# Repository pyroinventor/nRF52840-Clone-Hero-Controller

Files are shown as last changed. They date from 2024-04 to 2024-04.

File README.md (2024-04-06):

# nRF52840-Clone-Hero-Controller

This is a custom BLE enabled clone hero (or other rythm game) controller built around a xiao nRF52840 board.

## Why did I build this?

I played Lego Rock Band on the wii as a kid, and recently discovered clone hero as an alternative that allows you to play custom songs, make your own charts, and can run on a potato. However, the cheap wii controllers I had were annoying to use with their membrane switches, chunky usb reciever, and unweildy size. This motivated me to build a custom guitar controller with mechanical switches, BLE for battery life, and a body of my own design.

   
  
Nostalgic, but improvable :)

## What's Clone Hero?

Clone hero is a rythm game similar to guitar hero or rock band. It's open source and can run on pretty much any computer.

  
  

You can configure almost any device to be used as an input, such as MIDI drums and keyboards, gamepads, or in my case a custom controller. 

  
  
  
  

## Why nRF52840?

I initially used an ESP32 for development and testing, but it ended up being too bulky and power hungry to run on the tiny lipo battery I wanted to use. This led me to choose the nRF52840 from Nordic Semiconductors. The nordic controller supports bluetooth low energy, it takes up about a quarter of the size, and sips power compared to an ESP32 even while transmitting (30mA vs 200+mA). It is a little more expensive, costing around $10 to the ESP32's $3, but the previously mentioned advantages make it worth the premium for me. 

  \
<a href="https://www.seeedstudio.com/Seeed-XIAO-BLE-nRF52840-p-5201.html">nRF52840 I used</a>                         
<a href="https://www.aliexpress.us/item/2251832863673404.html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">ESP32 I used</a>

## Body Design

To design the body, I traced an image of a stratocaster in Onshape, then after fixing some weird unruly spline points I was able to extrude it and add some triangular cutouts. It wasn't too difficult but it took a while to do by hand. The fretboard and headstock were designed the same way. 

  
   

 Here's the tele I designed. 
 
   

The strum bar was a little tricky to dial in and it took a few revisions, but this is what I landed on. 

   

## Parts

* 1 x Xiao nRF52840
* 8 x Low Profile Mechanical Switches (I used Gateron LP Reds)
  * 5 for frets, 2 for strum bar, and 1 for start
* Few feet of cat5 cable or several lengths of wire (9 conductors total)
* 14AWG Steel Wire or similar for strum bar axle
* 2 x small washers to fit wire 
* 3D Printer / filament
All parts can be found in the STLs folder

## Build
Note: This guide assumes the reader can route wires and solder given the appropriate connections

### 1. Print all the parts and see how they go together. You should have 11 total:

* 5 keycaps
* 1 start button
* Headstock
* Fretboard
* Mounting plate
* Strum bar
* Strum body
* Guitar body
  


### 2. Bond the mounting plate and headstock to the fretboard
I used a 3D printing pen, but a soldering iron or CA glue should work as well.

 

This is also a good opportunity to run the wires for the switches through the mounting plate holes. I used a common ground and 5 conductors running to a cat5 cable. You should see a wire route running along the back of the fretboard for this cable.

### 3. Solder the switches on and snap them into the mounting plate

  

At this point you can also press fit the key caps onto the switches. The mounting plate and keycaps might require some sanding to get a perfect fit. You should end up with something like this ⬆️.

### 4. Route cable / wires for fretboard

Here's the cable running down the fretboard: 

 

I used a soldering iron to punch a hold through the point where the cable route meets the guitar body: 

 

### 5. Assemble strum bar / mount to guitar body

The switches should snap into the strum body, then the strum bar can be secured via the steel wire axle and some washers. 

 

Here are the wires leading to the strum bar: 

 

### 5. Soldering nRF52840 and start button

Here's the start button. I don't have it mounted, it just runs through one of the triangles :)

 

Here are the cat5 conductors soldered on to the nRF52840: \
I would recommend soldering onto removable header pins to make troubleshooting easier. 

 

It doesn't matter too much which pins you use (besides ground) as long as they're configured correctly in the software. \
Conveniently, the nRF board has internal pullup resistors so no additional circuitry is required. \
I added a couple male jumper wires to the board's battery pads to connect to a 1s lipo cell, but it can also be powered via USB.

That's about it for the main build 🎉

## Software

The arduino sketch I've included is built around Adafruit's library for their Bluefruit nRF52 feather boards. While this isn't the exactly what this project uses, the code still works just fine. HID support comes from the Adafruit TinyUSB Arduino library. \
The main thing you might have to change is buttonPins:

```
const int buttonPins[] = {0, 1, 2, 3, 4, 5, 6, 7};  // GPIO pin numbers for buttons
```
Just set these values to whatever pins you soldered the fret, strum, and start buttons to. The actual button asignments are calibrated in Clone Hero. \
You will probably have to add the Xiao nRF52840 board manually, in the arduino ide just go to Tools/Board/Boards Manager and search for Seeed nRF52 Boards. 

 

And there you have it! Once you've set the GPIO pins and selected the correct board and COM port you should be good to upload. \
Once everthing is up and running, you should be able to pair to your computer, assign the buttons in Clone Hero, and start jamming!

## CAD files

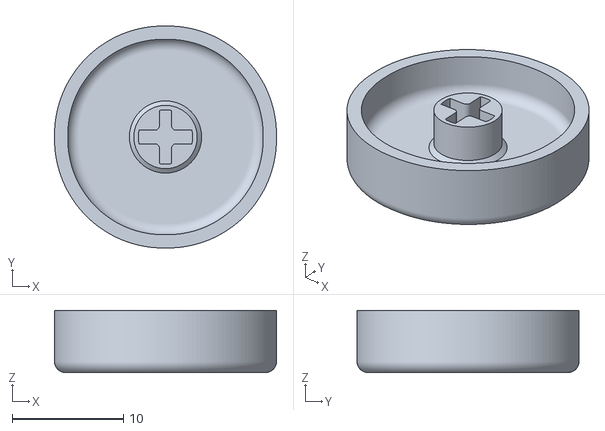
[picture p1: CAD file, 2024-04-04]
STLs/startCap.stl
20.0 x 20.0 x 5.60

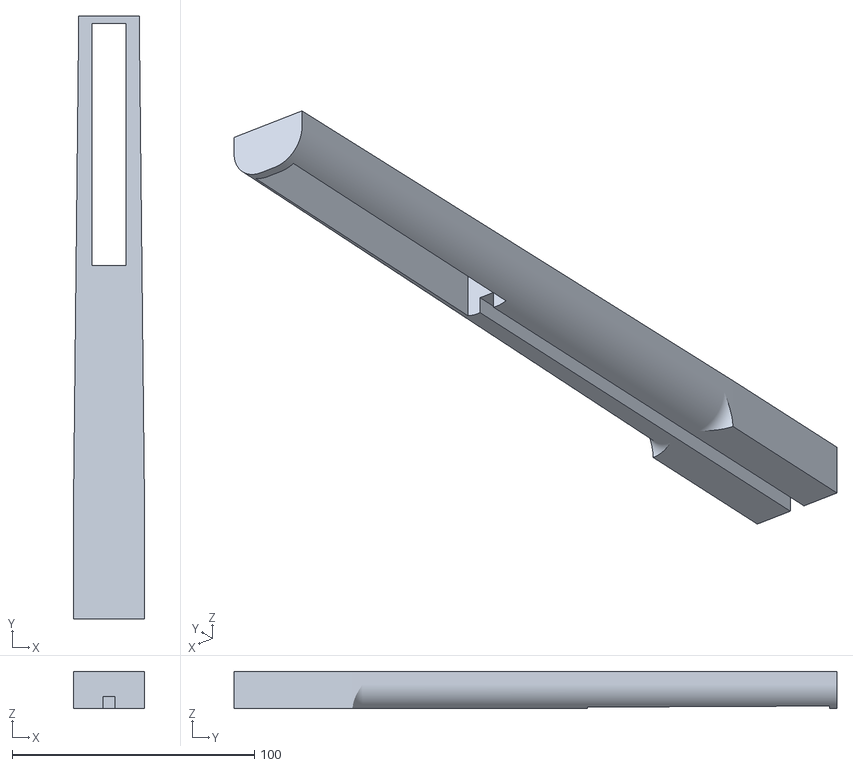
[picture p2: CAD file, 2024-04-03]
STLs/teleNeck.stl
29.3 x 249.0 x 15.3

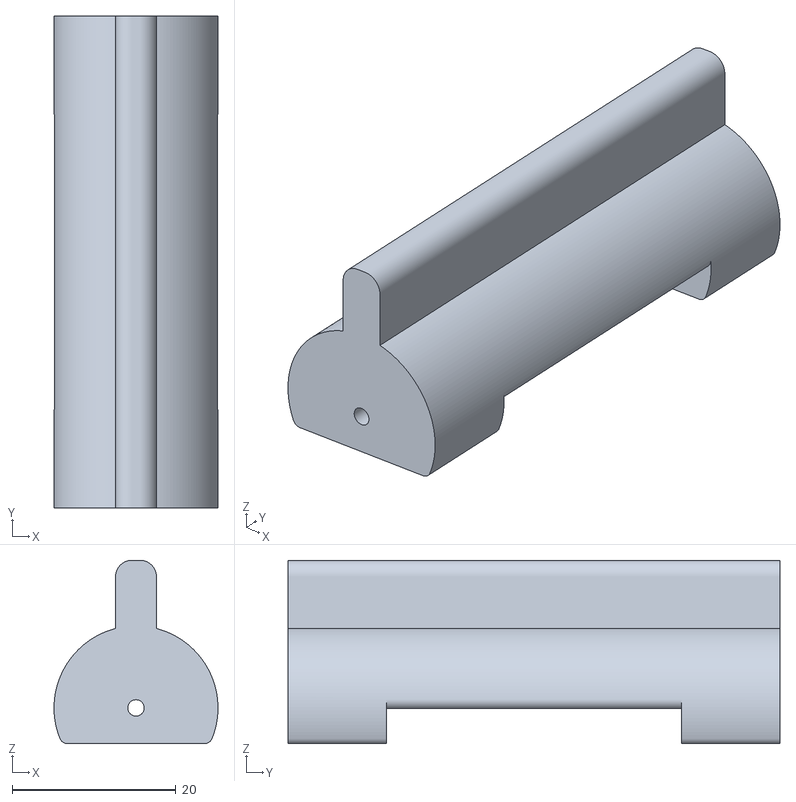
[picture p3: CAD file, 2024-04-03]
STLs/strumBar.stl
20.0 x 60.0 x 22.4

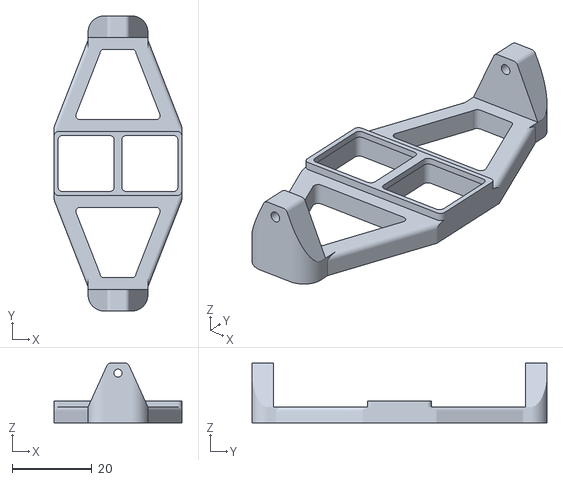
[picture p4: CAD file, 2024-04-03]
STLs/strumBody.stl
32.0 x 74.0 x 15.0

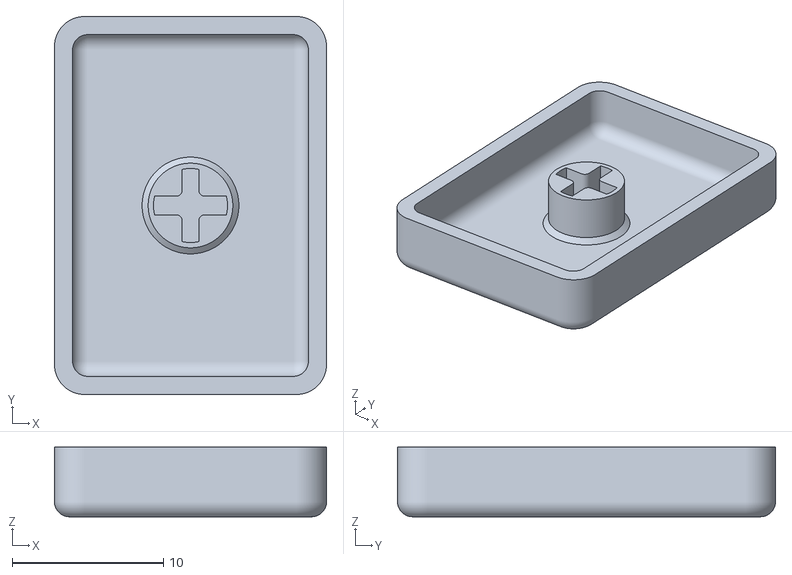
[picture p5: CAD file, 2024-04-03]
STLs/switchCap.stl
18.0 x 25.0 x 4.60

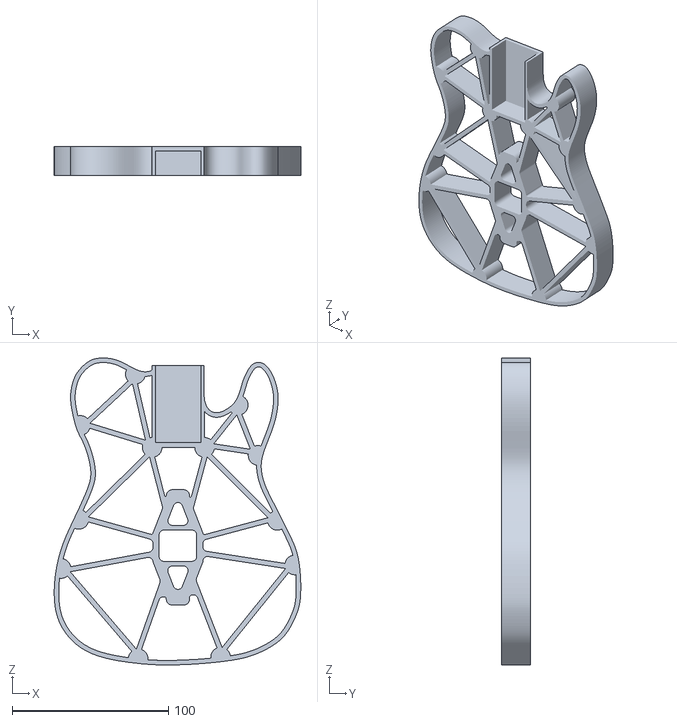
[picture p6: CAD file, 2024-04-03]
STLs/teleBody.stl
158.1 x 18.4 x 196.7

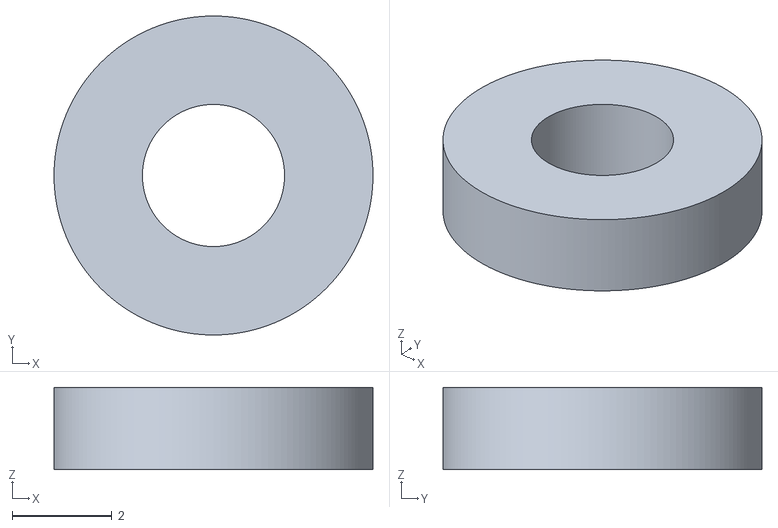
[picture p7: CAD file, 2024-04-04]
STLs/washer.stl
6.40 x 6.40 x 1.65

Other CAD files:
STLs/teleHeadstock.stl

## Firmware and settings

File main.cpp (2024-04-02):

#include <Arduino.h>
#include <Bounce2.h>
//#include <FastLED.h>

#define numOfButtons 8

Bounce debouncers[numOfButtons];

byte buttonPins[numOfButtons] = {0, 4, 16, 17, 5, 18, 19, 21};
byte physicalButtons[numOfButtons] = {1, 2, 3, 4, 5, 6, 7, 8};

void setup()
{
    for (byte currentPinIndex = 0; currentPinIndex < numOfButtons; currentPinIndex++)
    {
        pinMode(buttonPins[currentPinIndex], INPUT_PULLUP);

        debouncers[currentPinIndex] = Bounce();
        debouncers[currentPinIndex].attach(buttonPins[currentPinIndex]);
        debouncers[currentPinIndex].interval(5);
    }

    Serial.begin(115200);
}

void loop()
{
    bool sendReport = false;

    for (byte currentIndex = 0; currentIndex < numOfButtons; currentIndex++)
    {
        debouncers[currentIndex].update();

        if (debouncers[currentIndex].fell())
        {
            Serial.write(physicalButtons[currentIndex]);
            sendReport = true;
            // Add code to handle LED feedback if needed
        }
        else if (debouncers[currentIndex].rose())
        {
            Serial.write(physicalButtons[currentIndex] | 0x80); // Release event
            sendReport = true;
            // Add code to handle LED feedback if needed
        }
    }

    if (sendReport)
    {
        delay(5); // Add a small delay to ensure that the data is sent properly
    }
}

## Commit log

2024-04-03 Create stl
2024-04-03 Update and rename stratBody.stl to stratBody.stl
    [stratBody.stl]
2024-04-03 Rename stratHeadstock.stl to STLs /stratHeadstock.stl
    [stratHeadstock.stl]
2024-04-03 Update and rename stratHeadstock.stl to stratHeadstock.stl
    [stratHeadstock.stl]
